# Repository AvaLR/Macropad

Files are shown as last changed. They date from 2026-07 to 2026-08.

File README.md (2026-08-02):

# Macropad

PCB:
- Started to design this in KiCad starting with the skematic design and then moving to the PCB design.
- I originally started with a 3X4 with 2 rotary encoders and 1 OLED
- I wanted to add LEDs so I removed 1 rotary encoder and made the other rotary encoder's button the same as button 3. Also made it a 3X3 instead of a 3X4.
- Wiring was a challenge and reminded me of that Flow Free game so it was kinda fun in that aspect.
Screenshot 2026-07-26 at 11 47 30 AM
Screenshot 2026-07-26 at 11 47 11 AM
Screenshot 2026-07-26 at 11 45 51 AM

Enclosure:
- A lot easier then the PCB
- First I inserted a .step file of my PCB into AutoDesk Fusion 
- Then based on the PCB I made my bottom enclosure (120mm X 100mm X 13mm) with 2.9mm holes in each corner so I can add screws to put my top and bottom enclosures together. I also put a hole on back for the USB.
- After I made the bottom enclosure I created the top enclosure with holes for all my buttons (inserting my PCB design really helped for this part because I knew exactly where the holes went). I put 2.9mm holes here as well to again be able to put the top and bottom together. 
- The top enclosure was a 120mm x 100mm x 3mm so with the top and bottom enclosure together it turned into a 120mm x 100mm x 16mm enclosure.
Screenshot 2026-07-26 at 11 55 19 AMScreenshot 2026-07-26 at 11 55 47 AM Screenshot 2026-07-26 at 11 55 33 AM

Firmware:
- Created 3 layers of Buttons: Daily, AVTF & Coding
- Each layer does different things that will make my life easier from study time to coding to editing videos!
- Each layer has its own RGB unkeyglow color, and the OLED will show what the layer I'm on
  Screenshot 2026-08-02 at 5 45 00 PM

Credit: 
- Info & Guide - Hack Club
- PCB, Enclosure, Firmware - Ava Russell using QMK Resources/Code/Guide
- Debugging Help - AI

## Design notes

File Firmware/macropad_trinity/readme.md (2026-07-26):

# macropad_trinity

macropad_trinity

*A short description of the keyboard/project*

* Keyboard Maintainer: [Ava Russell](https://github.com/AvaLR)
* Hardware Supported: *The PCBs, controllers supported*
* Hardware Availability: *Links to where you can find this hardware*

Make example for this keyboard (after setting up your build environment):

    make macropad_trinity:default

Flashing example for this keyboard:

    make macropad_trinity:default:flash

See the [build environment setup](https://docs.qmk.fm/#/getting_started_build_tools) and the [make instructions](https://docs.qmk.fm/#/getting_started_make_guide) for more information. Brand new to QMK? Start with our [Complete Newbs Guide](https://docs.qmk.fm/#/newbs).

## Bootloader

Enter the bootloader in 3 ways:

* **Bootmagic reset**: Hold down the key at (0,0) in the matrix (usually the top left key or Escape) and plug in the keyboard
* **Physical reset button**: Briefly press the button on the back of the PCB - some may have pads you must short instead
* **Keycode in layout**: Press the key mapped to `QK_BOOT` if it is available

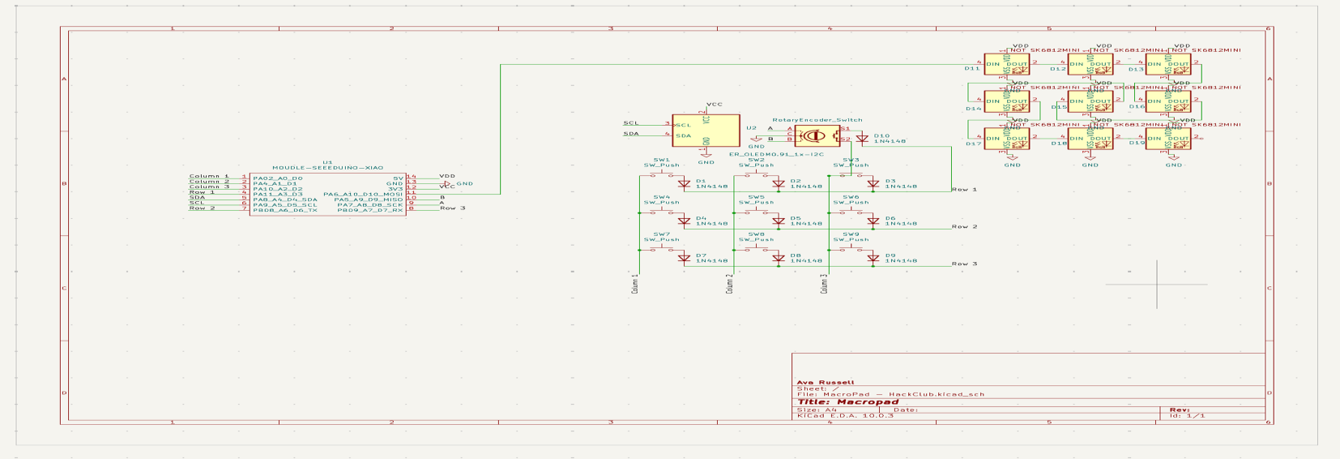
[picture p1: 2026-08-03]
Images/schematic.png

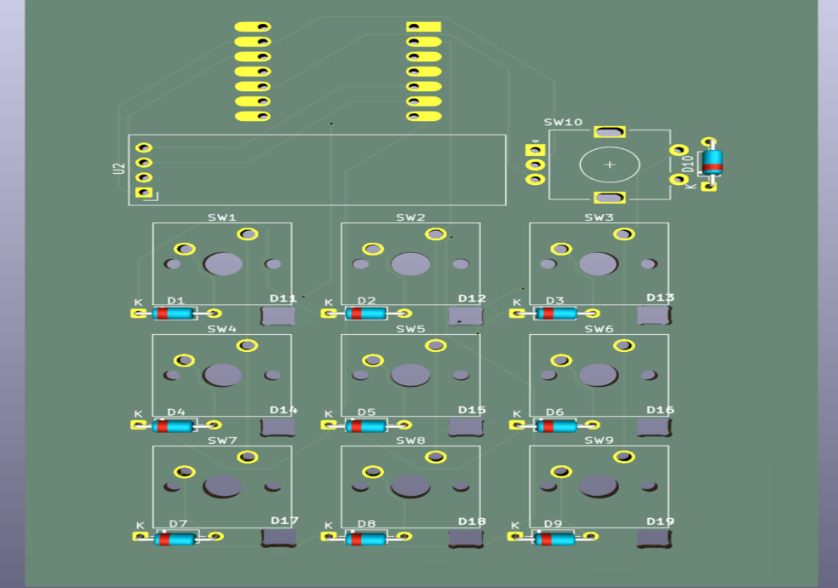
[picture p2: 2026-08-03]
Images/3d_image_pcb.png

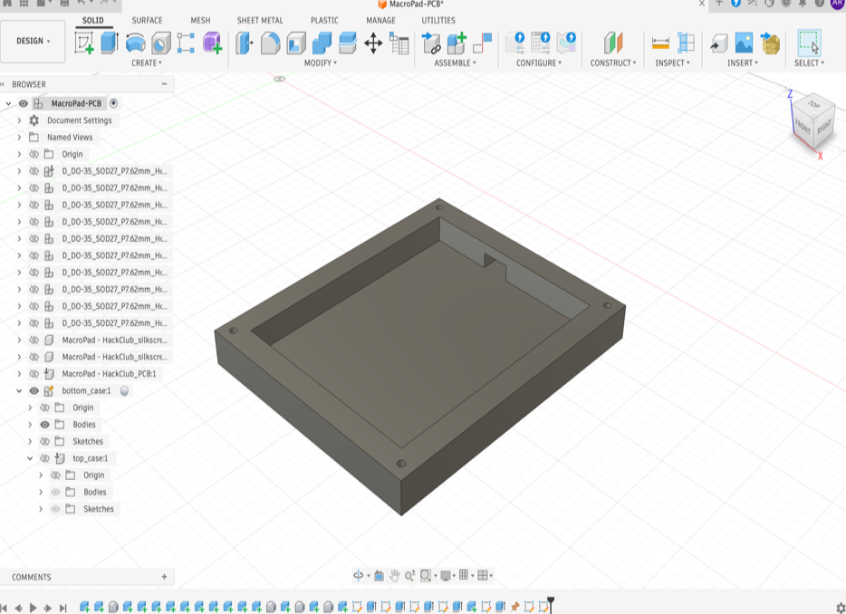
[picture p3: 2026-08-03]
Images/bottom enclosure.png

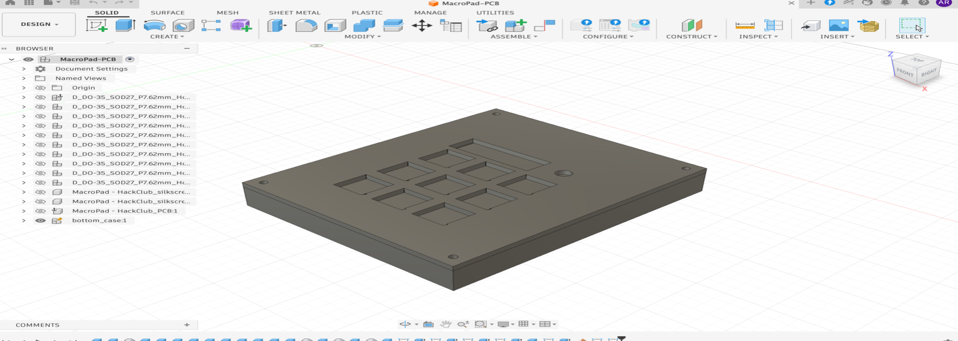
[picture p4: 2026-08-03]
Images/whole_enclosure.png

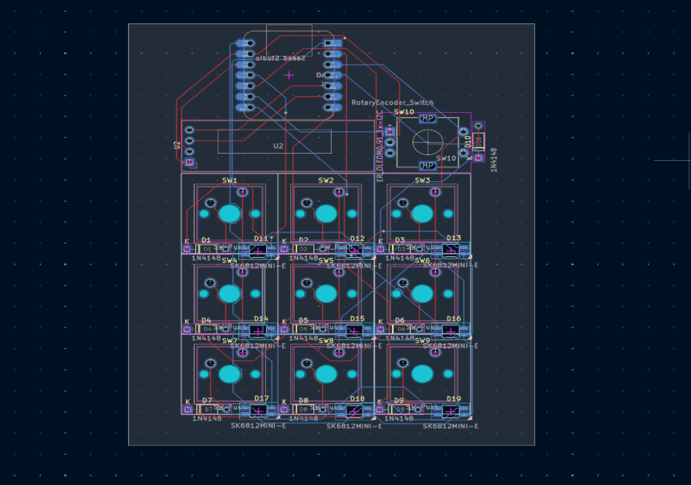
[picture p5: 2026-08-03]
Images/wired_pcb.png

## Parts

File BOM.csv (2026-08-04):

Item | Quantity | Price | Link
Seeed Studio XIAO RP2040 Microcontroller | 1 | $4.90 | https://digikey.com
Gateron Mechanical Switches (Pack of 10) | 1 | $3.50 | https://aliexpress.com
Blank DSA Keycaps (Pack of 10) | 1 | $4.60 | https://aliexpress.com
0.91 inch I2C OLED Display Module | 1 | $2.10 | https://aliexpress.com
EC11 Rotary Encoder with Switch and Knob | 1 | $2.50 | https://aliexpress.com
WS2812B 5050 RGB LED Chips (Pack of 10) | 1 | $2.90 | https://aliexpress.com
Custom PCB Fabrication (5 Pack via JLCPCB) | 1 | $2.00 | https://jlcpcb.com
DHL/FedEx International PCB Shipping | 1 | $16.00 | N/A
Estimated Component Shipping & Taxes | 1 | $6.50 | N/A

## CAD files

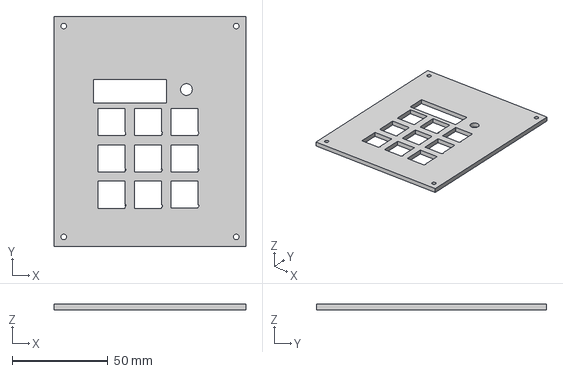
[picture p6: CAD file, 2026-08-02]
Enclosure/MacroPad-PCB.step
100.0 x 120.0 x 3.00 mm

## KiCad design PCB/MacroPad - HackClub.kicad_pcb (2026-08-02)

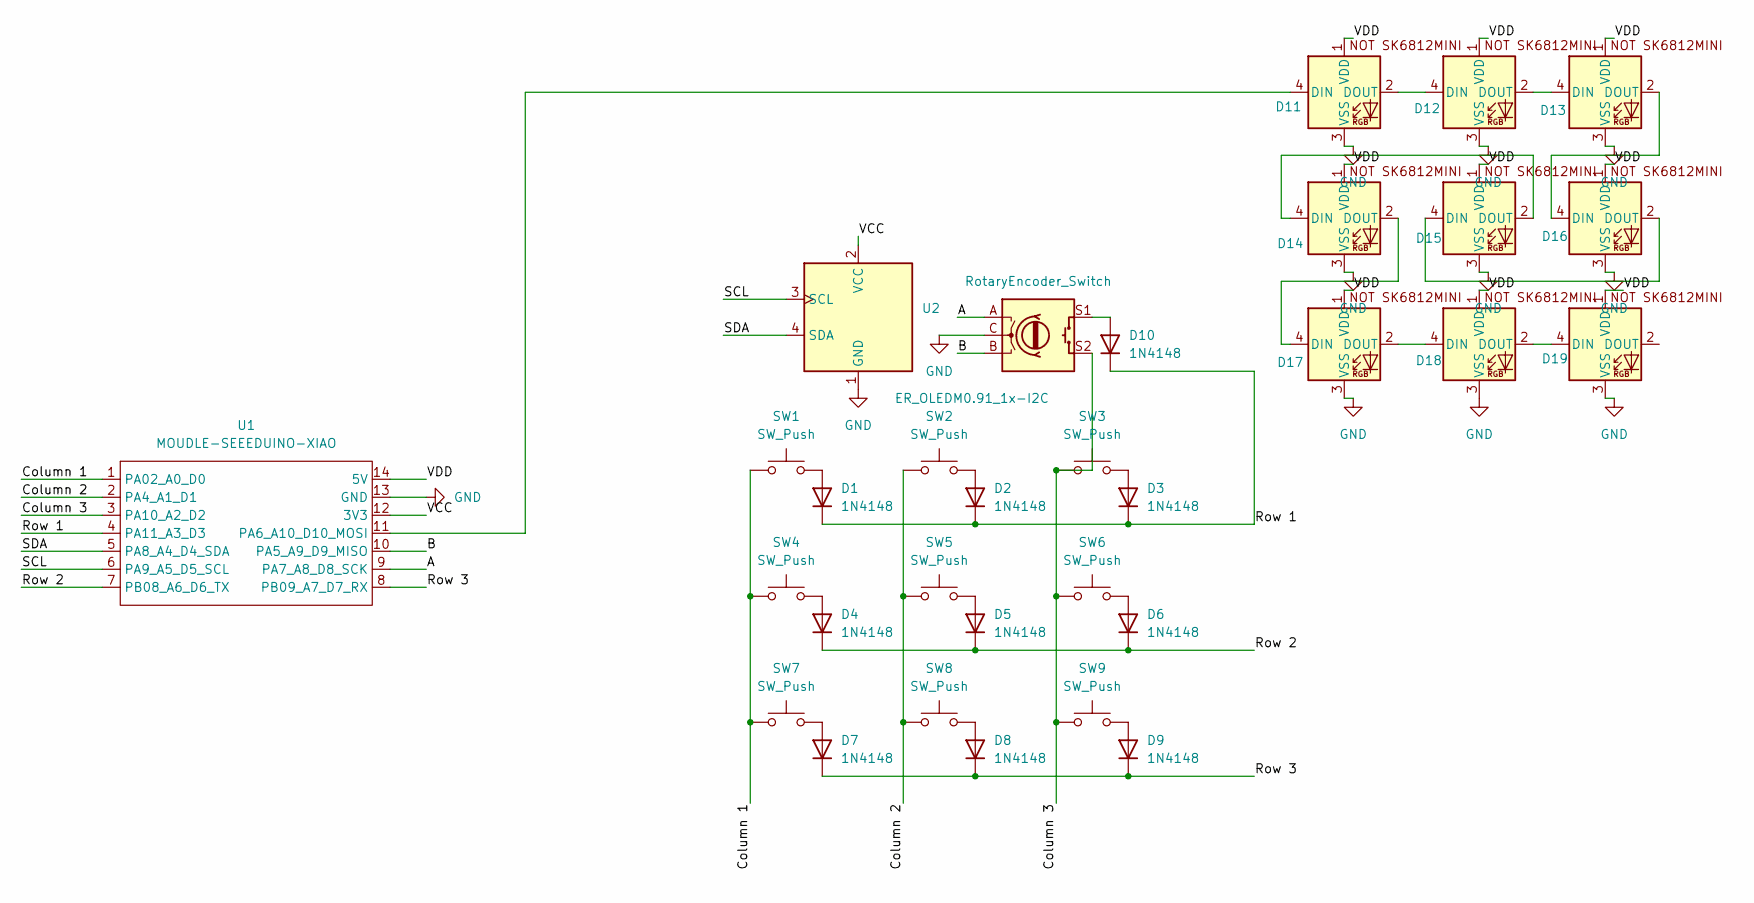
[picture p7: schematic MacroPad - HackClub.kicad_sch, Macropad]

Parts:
D1, D2, D3, D4, D5, D6, D7, D8, D9, D10: 1N4148; D_DO-35_SOD27_P7.62mm_Horizontal
D11, D12, D13, D14, D15, D16, D17, D18, D19: SK6812MINI-E; SK6812MINI-E_fixed
SW1, SW2, SW3, SW4, SW5, SW6, SW7, SW8, SW9: SW_Push; SW_Cherry_MX_1.00u_PCB
SW10: RotaryEncoder_Switch; RotaryEncoder_Alps_EC11E-Switch_Vertical_H20mm
U1: MOUDLE-SEEEDUINO-XIAO; XIAO-Generic-Hybrid-14P-2.54-21X17.8MM
U2: ER_OLEDM0.91_1x-I2C

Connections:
/A: SW10.A, U1.9 (PA7_A8_D8_SCK)
/B: SW10.B, U1.10 (PA5_A9_D9_MISO)
/Column 1: SW1.1, SW4.1, SW7.1, U1.1 (PA02_A0_D0)
/Column 2: SW2.1, SW5.1, SW8.1, U1.2 (PA4_A1_D1)
/Column 3: SW3.1, SW6.1, SW9.1, SW10.S2, U1.3 (PA10_A2_D2)
/Row 1: D1.1 (K), D2.1 (K), D3.1 (K), D10.1 (K), U1.4 (PA11_A3_D3)
/Row 2: D4.1 (K), D5.1 (K), D6.1 (K), U1.7 (PB08_A6_D6_TX)
/Row 3: D7.1 (K), D8.1 (K), D9.1 (K), U1.8 (PB09_A7_D7_RX)
/SCL: U1.6 (PA9_A5_D5_SCL), U2.3 (SCL)
/SDA: U1.5 (PA8_A4_D4_SDA), U2.4 (SDA)
/VCC: U1.12 (3V3), U2.2 (VCC)
/VDD: D11.1 (VDD), D12.1 (VDD), D13.1 (VDD), D14.1 (VDD), D15.1 (VDD), D16.1 (VDD), D17.1 (VDD), D18.1 (VDD), D19.1 (VDD), U1.14 (5V)
GND: D11.3 (VSS), D12.3 (VSS), D13.3 (VSS), D14.3 (VSS), D15.3 (VSS), D16.3 (VSS), D17.3 (VSS), D18.3 (VSS), D19.3 (VSS), SW10.C, U1.13 (GND), U2.1 (GND)
unnamed: D1.2 (A), SW1.2
unnamed: D2.2 (A), SW2.2
unnamed: D3.2 (A), SW3.2
unnamed: D4.2 (A), SW4.2
unnamed: D5.2 (A), SW5.2
unnamed: D6.2 (A), SW6.2
unnamed: D7.2 (A), SW7.2
unnamed: D8.2 (A), SW8.2
unnamed: D9.2 (A), SW9.2
unnamed: D10.2 (A), SW10.S1
unnamed: D11.4 (DIN), U1.11 (PA6_A10_D10_MOSI)
unnamed: D11.2 (DOUT), D12.4 (DIN)
unnamed: D12.2 (DOUT), D13.4 (DIN)
unnamed: D13.2 (DOUT), D16.4 (DIN)
unnamed: D14.4 (DIN), D15.2 (DOUT)
unnamed: D14.2 (DOUT), D17.4 (DIN)
unnamed: D15.4 (DIN), D16.2 (DOUT)
unnamed: D17.2 (DOUT), D18.4 (DIN)
unnamed: D18.2 (DOUT), D19.4 (DIN)

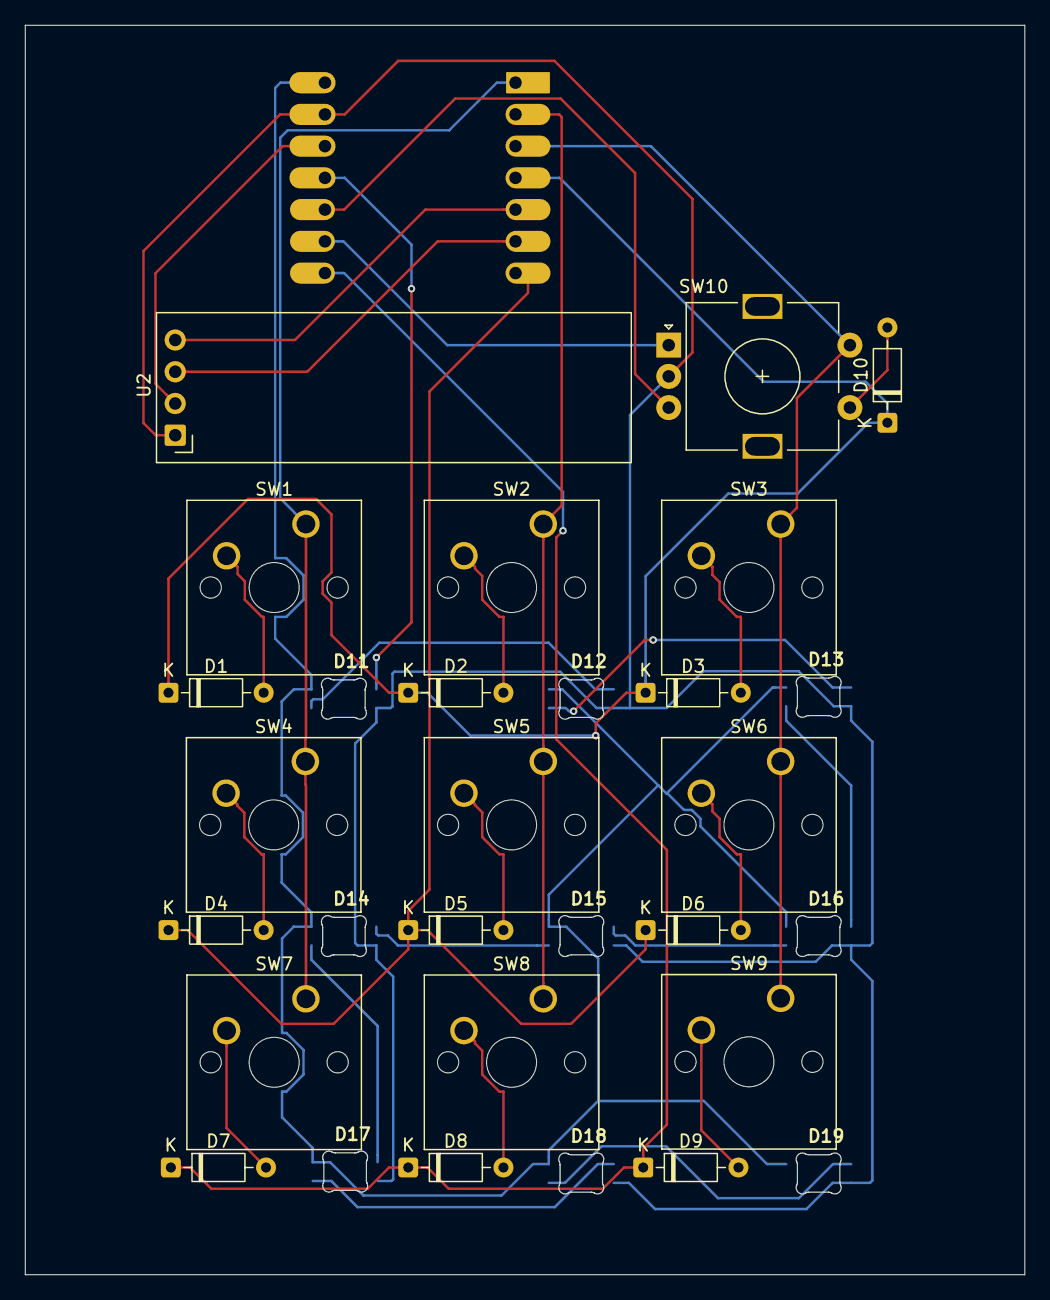
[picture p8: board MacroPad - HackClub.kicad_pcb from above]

Board: 2 copper layers, 80.0 x 100.0 mm, 31 parts (1 on the bottom side), 32 nets.

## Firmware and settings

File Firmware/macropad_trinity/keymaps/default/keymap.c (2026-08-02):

//Copyright 2023 QMK
// SPDX-License-Identifier: GPL-2.0-or-later
#include QMK_KEYBOARD_H

// Identify standard custom layers
enum custom_layers {
    _DAILY,
    _AVTF,
    _CODING
};

// Map hotkey macros to single internal words
enum custom_keycodes {
    MIN_ALL = SAFE_RANGE,
    OPEN_MUSIC,
    OPEN_NOTES,
    RIPPLE_DEL,
    AUTO_FIX_COLOR,
    SLICE_TOOL,
    SELECT_TOOL,
    NEW_TEXT,
    SPEED_DUR,
    LINK_UNLINK,
    RUN_TERM,
    AUTO_FORMAT,
    CLOSE_TERM,
    GIT_ADD,
    GIT_COMMIT,
    GIT_PUSH,
    OPEN_VSCODE,
    OPEN_COURSERA
};

// Simple 3x3 Grid Layout Arrays
const uint16_t PROGMEM keymaps[][MATRIX_ROWS][MATRIX_COLS] = {
    [_DAILY] = LAYOUT_ortho_3x3(
        MIN_ALL,    OPEN_MUSIC, KC_MUTE,
        KC_MPRV,    KC_MPLY,    KC_MNXT,
        KC_PSCR,    OPEN_NOTES, TG(_AVTF)
    ),
    [_AVTF] = LAYOUT_ortho_3x3(
        RIPPLE_DEL, AUTO_FIX_COLOR, KC_MPLY,
        SLICE_TOOL, SELECT_TOOL,    NEW_TEXT,
        SPEED_DUR,  LINK_UNLINK,    TG(_CODING)
    ),
    [_CODING] = LAYOUT_ortho_3x3(
        RUN_TERM,    AUTO_FORMAT,  CLOSE_TERM,
        GIT_ADD,     GIT_COMMIT,   GIT_PUSH,
        OPEN_VSCODE, OPEN_COURSERA, TG(_AVTF)
    )
};

// Basic Vol Down / Vol Up mapping for turning the wheel left or right
#if defined(ENCODER_ENABLE) && defined(ENCODER_MAP_ENABLE)
const uint16_t PROGMEM encoder_map[][NUM_ENCODERS][NUM_DIRECTIONS] = {
    [_DAILY]  = { ENCODER_CCW_CW(KC_VOLD, KC_VOLU) },
    [_AVTF]   = { ENCODER_CCW_CW(KC_VOLD, KC_VOLU) },
    [_CODING] = { ENCODER_CCW_CW(KC_VOLD, KC_VOLU) }
};
#endif

// Hotkey Macro Strings execution block
bool process_record_user(uint16_t keycode, keyrecord_t *record) {
    if (record->event.pressed) {
        switch (keycode) {
            case MIN_ALL:        SEND_STRING(SS_DOWN(X_LGUI) "d" SS_UP(X_LGUI)); return false;
            case OPEN_MUSIC:     SEND_STRING(SS_DOWN(X_LGUI) "1" SS_UP(X_LGUI)); return false;
            case OPEN_NOTES:     SEND_STRING(SS_TAP(X_LGUI) SS_DELAY(50) "notepad" SS_TAP(X_ENTER)); return false;
            case RIPPLE_DEL:     SEND_STRING(SS_DOWN(X_LALT) SS_TAP(X_BSPC) SS_UP(X_LALT)); return false;
            case AUTO_FIX_COLOR: SEND_STRING(SS_DOWN(X_LCTRL) SS_TAP(X_F) SS_UP(X_LCTRL)); return false;
            case SLICE_TOOL:     SEND_STRING("c"); return false;
            case SELECT_TOOL:    SEND_STRING("v"); return false;
            case NEW_TEXT:       SEND_STRING("t"); return false;
            case SPEED_DUR:      SEND_STRING(SS_DOWN(X_LCTRL) "r" SS_UP(X_LCTRL)); return false;
            case LINK_UNLINK:    SEND_STRING(SS_DOWN(X_LCTRL) "l" SS_UP(X_LCTRL)); return false;
            case RUN_TERM:       SEND_STRING(SS_DOWN(X_LCTRL) "`" SS_UP(X_LCTRL)); return false;
            case AUTO_FORMAT:    SEND_STRING(SS_DOWN(X_LALT) SS_DOWN(X_LSHIFT) "f" SS_UP(X_LSHIFT) SS_UP(X_LALT)); return false;
            case CLOSE_TERM:     SEND_STRING("exit" SS_TAP(X_ENTER)); return false;
            case GIT_ADD:        SEND_STRING("git add ." SS_TAP(X_ENTER)); return false;
            case GIT_COMMIT:     SEND_STRING("git commit -m \"\""); return false;
            case GIT_PUSH:       SEND_STRING("git push" SS_TAP(X_ENTER)); return false;
            case OPEN_VSCODE:    SEND_STRING(SS_TAP(X_LGUI) SS_DELAY(50) "code" SS_TAP(X_ENTER)); return false;
            case OPEN_COURSERA:  SEND_STRING(SS_TAP(X_LGUI) SS_DELAY(50) "browser" SS_DELAY(100) "coursera.org" SS_TAP(X_ENTER)); return false;
        }
    }
    return true;
}

// Simple OLED Screen Display Status Tracker
#ifdef OLED_ENABLE
bool oled_task_user(void) {
    switch (get_highest_layer(layer_state)) {
        case _DAILY:  oled_write_P(PSTR("LAYER: DAILY\n"), false); break;
        case _AVTF:   oled_write_P(PSTR("LAYER: AVTF EDIT\n"), false); break;
        case _CODING: oled_write_P(PSTR("LAYER: CODING\n"), false); break;
    }
    return false;
}
#endif

// Simple LED Layer Tracker Color Interceptor
#ifdef RGBLIGHT_ENABLE
layer_state_t layer_state_set_user(layer_state_t state) {
    switch (get_highest_layer(state)) {
        case _DAILY:  rgblight_setrgb(0, 225, 255); break; // Cyan
        case _AVTF:   rgblight_setrgb(255, 180, 200); break; // Pastel Pink
        case _CODING: rgblight_setrgb(211, 211, 255);  break; // Lavender
    } 
    return state;
}
void keyboard_post_init_user(void) {
    rgblight_enable();
    rgblight_mode(RGBLIGHT_MODE_STATIC_LIGHT);
    rgblight_setrgb(0, 180, 255);
}
#endif
        

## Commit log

2026-08-02 PCB & Schematic Upload
    [MacroPad - HackClub.kicad_pcb, MacroPad - HackClub.kicad_sch]
2026-08-02 Enclosure Upload
    [MacroPad-PCB.step]
